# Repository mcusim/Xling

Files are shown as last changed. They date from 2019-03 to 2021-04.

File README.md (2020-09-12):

# Xling, a pocket demon



This is a little tamagotchi-like toy I've created for my wife. I used to think
that this is how a modern Tamagotchi could look like initially. However, it can
also be used as a battery-powered DIY platform to experiment with FreeRTOS and
graphics.

## Specifications

  * 35x47mm board
  * Monochrome OLED 128x64px
  * Low energy consumption (~20mA @ active, 0.75mA @ sleep)
  * Hand-soldering friendly (TQFP-44 0.8mm pitch, smallest is 0603)
  * 3D-printable case
  * Open Source Hardware/Firmware

## Hardware

  * ATmega1284P 8-bit AVR MCU with 128 KiB flash and 16 KiB SRAM
  * SH1106G display controller
  * MCP73831 charge controller
  * AP3401 DC-DC buck converter
  * 400mAh 3.7V Li-Po battery (~26h @ active, ~30 days @ sleep)
  * Load-sharing circuit (can be powered by USB or battery, like a smartphone)
  * KiCad 5.1.0 project for schematic and board designs
  * Released under CERN-OHL-W v2 (Rev. 4) and CC-BY-SA (before Rev. 4)



## Software

Please, note that the software part of the project isn't finished yet!

  * Shows a frame time, energy left and a battery charged status
  * Animation with Exy-in-the-bottle, a "personal daemon"
  * Programmed in C99 using the FreeRTOS kernel modified for ATmega1284P
  * There are three tasks only: Display, Battery Monitor and Sleep Mode
  * Released under GNU GPLv3+

## Website and Contact

Hackaday.io project: https://hackaday.io/project/165726-xling    
Email: dsl AT mcusim DOT org    
Dmitry Salychev

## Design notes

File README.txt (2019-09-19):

3d_models	.STEP and .WRL model files for all footprints
datasheets	data sheets for components used
gerber		final production files
images		SVG images and 3D board renders
lib_sch		schematic symbols
lib_fp.pretty	footprints
pdf		schematics, board layouts, dimension drawings

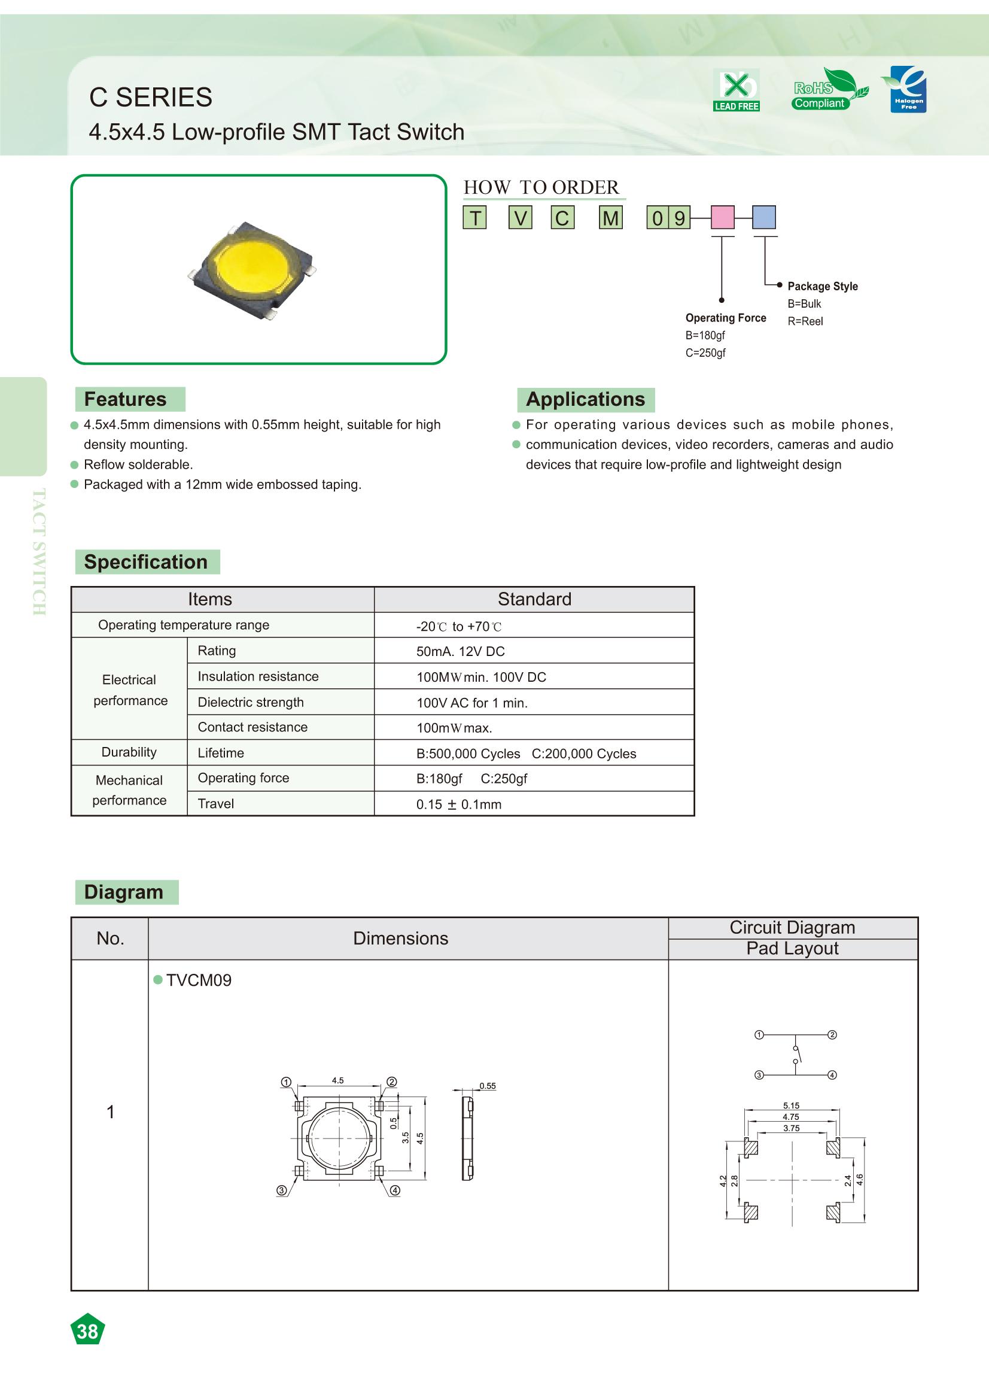
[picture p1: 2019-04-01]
hardware/datasheets/switch/TVCM09BB.jpg

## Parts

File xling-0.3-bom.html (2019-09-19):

Ref | Qnty | Value | Part | Footprint | Description | Vendor | Model
C1, C3, C4, C7, C10, C12 | 6 | 100nF | xling:C | Xling Footprints:C_0603_1608Metric |  |  | CL10B104KO8NNNC
C2, C11, C17, C18, C19, C20, C21 | 7 | 4.7uF | xling:C | Xling Footprints:C_0603_1608Metric |  |  | CL10A475KQ8NNNC
C5, C6, C16, C22 | 4 | 22pF | xling:C | Xling Footprints:C_0603_1608Metric |  |  | CL10C220JB8NNNC
C8, C9 | 2 | 0.22uF | xling:C | Xling Footprints:C_0603_1608Metric |  |  | CL10B224KO8NNNC
C13, C14, C15 | 3 | 4.7nF | xling:C | Xling Footprints:C_0603_1608Metric |  |  | CL10B472KB8NNNC
D1 | 1 | 1N5819 | xling:1N5818 | Xling Footprints:D_SOD-123 |  |  | 1N5819HW-7-F
J1 | 1 | ISP | xling:Conn_02x03_Odd_Even | Xling Footprints:Molex_Pico-Lock_504050-0691_1x06-1MP_P1.50mm_Horizontal |  |  | 504050-0691
J2 | 1 | USB_OTG | xling:USB_OTG | Xling Footprints:USB_Micro-B_Molex-105017-0001 |  |  | 105017-0001
J3 | 1 | Battery | xling:Conn_01x02 | Xling Footprints:Battery_SMD_pads_1x02_HandSoldering
L1 | 1 | 10uH | xling:L | Xling Footprints:L_1210_3225Metric |  |  | B82422A1103K100
L2 | 1 | 2.2uH | xling:L | Xling Footprints:L_1210_3225Metric |  |  | NLV32T-2R2J-PF
OH1 | 1 | OpenHardwareLogo | xling:OpenHardwareLogo | Xling Footprints:oshw
Q1 | 1 | NTR0202PL | xling:NTR2101P | Xling Footprints:SOT-23 |  |  | NTR0202PLT1G
R1, R2 | 2 | 1K | xling:R | Xling Footprints:R_0603_1608Metric |  |  | CRCW06031K00JNTABC
R3, R8, R9, R10, R11, R13 | 6 | 100K | xling:R | Xling Footprints:R_0603_1608Metric |  |  | 0603SAJ0104T5E
R4, R5, R6, R7, R12, R14, R15 | 7 | 510K | xling:R | Xling Footprints:R_0603_1608Metric |  |  | 0603SAJ0514T5E
R16 | 1 | 2.55K | xling:R | Xling Footprints:R_0603_1608Metric |  |  | 0603SAF2551T5E
R17, R18 | 2 | 110K | xling:R | Xling Footprints:R_0603_1608Metric |  |  | 0603SAF1103T5E
R19, R20 | 2 | 10K | xling:R | Xling Footprints:R_0603_1608Metric |  |  | 0603SAJ0103T5E
SW1, SW2, SW3 | 3 | BTN | xling:SW_Push | Xling Footprints:SW_Tact_4.5x4.5mm_TVCM09BB_Low_Profile |  |  | TVCM09BB
U1 | 1 | REX012864L | xling:REX012864L | Xling Footprints:DisplayPin_1x30_P0.7mm |  |  | REX012864LYAP3N00000
U2 | 1 | ATmega1284P-AU | xling:ATmega1284P-AU | Xling Footprints:TQFP-44_10x10mm_P0.8mm | 20MHz, 128kB Flash, 16kB SRAM, 4kB EEPROM, JTAG, TQFP-44 |  | ATMEGA1284P-AU
U3 | 1 | MCP73831 | xling:MCP73831 | Xling Footprints:MCP73831_SOT_23 |  |  | MCP73831T-2ATI/OT
U4 | 1 | AP3401_TSOT26 | xling:AP3401_TSOT26 | Xling Footprints:AP3401_TSOT26 | 1.5MHz, 1A DC-DC Buck Converter |  | AP3401KTTR-G1
Y1 | 1 | 12MHz | xling:Crystal_GND24 | Xling Footprints:Crystal_SMD_CFPX-104-4Pin_5x3.2mm | Four pin crystal, GND on pins 2 and 4 |  | LFXTAL032878BULK

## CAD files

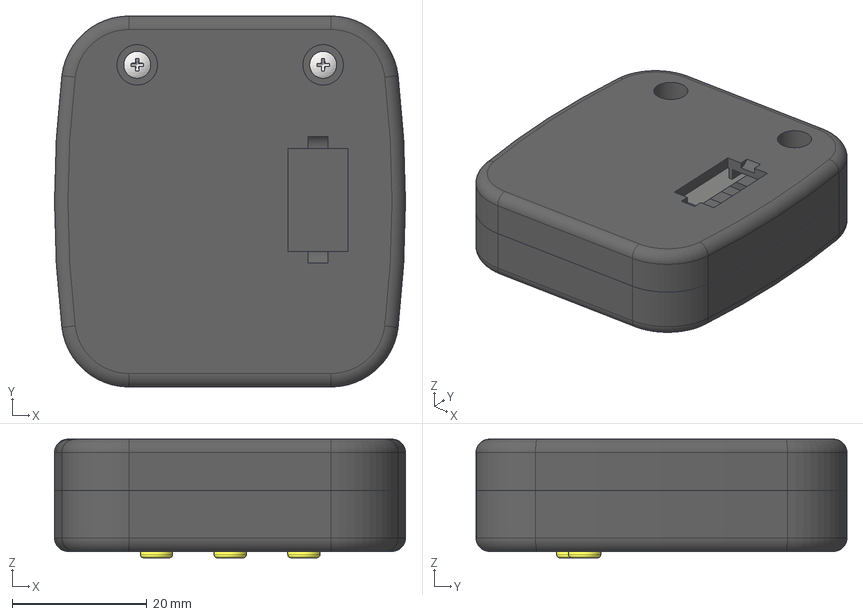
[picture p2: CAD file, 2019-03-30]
3d_models/xling_assembled_model.fcstd
52.0 x 55.0 x 17.6 mm
Display
Bottom_part
Top_part
Buttons
Battery
Screw1
Screw2

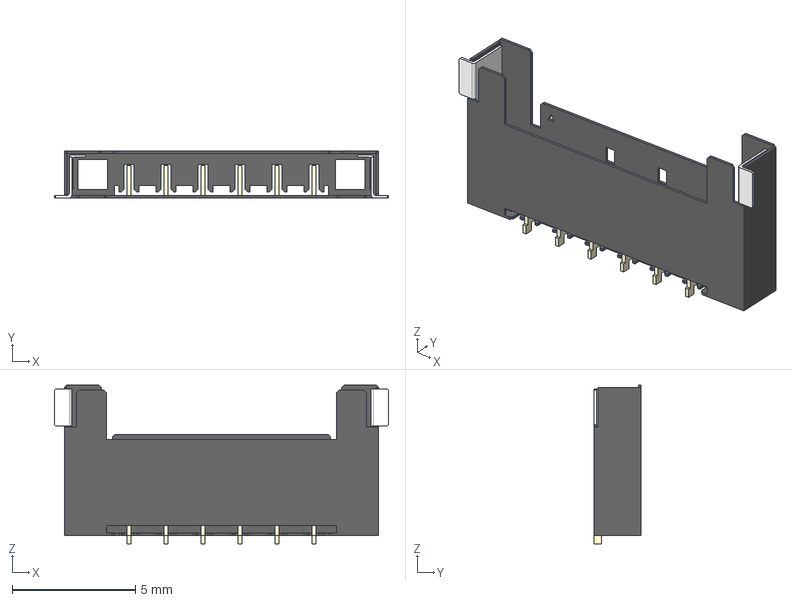
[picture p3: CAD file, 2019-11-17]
3d_models/packages/Molex_504050-0691.stp
13.5 x 1.90 x 6.44 mm

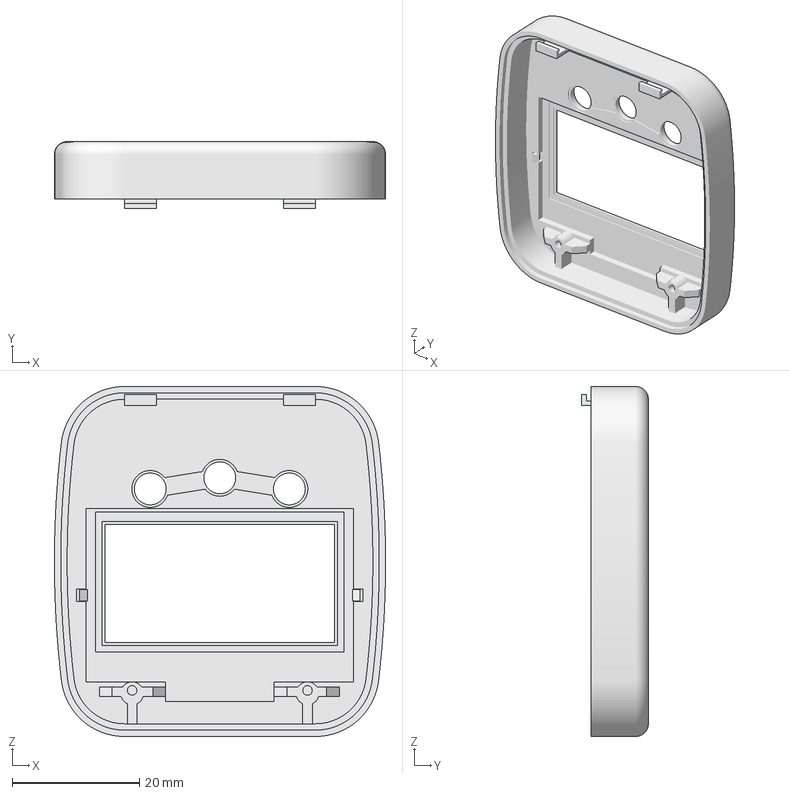
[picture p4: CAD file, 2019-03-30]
3d_models/Top_case_v8.FCStd
52.0 x 10.5 x 55.0 mm

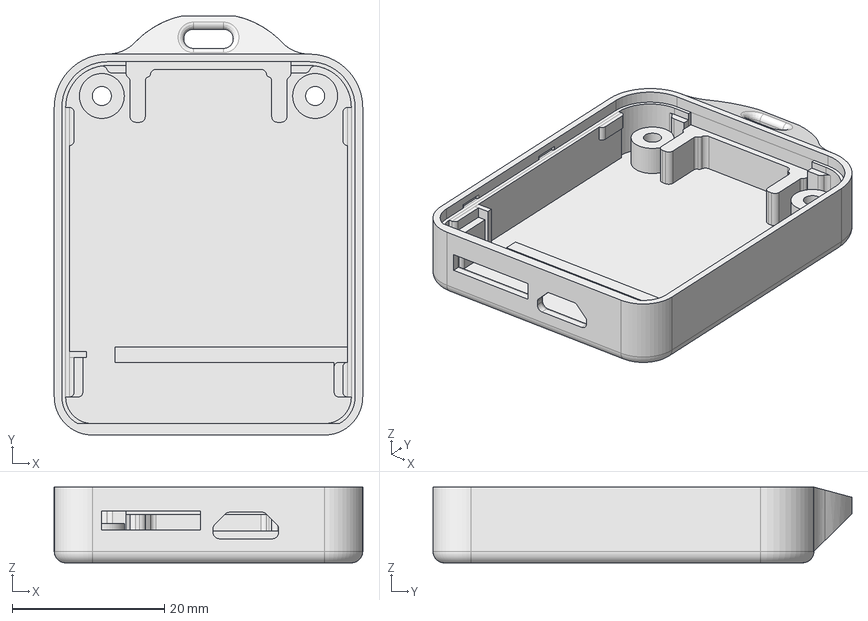
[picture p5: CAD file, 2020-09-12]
case/Bottom_case.FCStd
40.5 x 55.0 x 9.95 mm

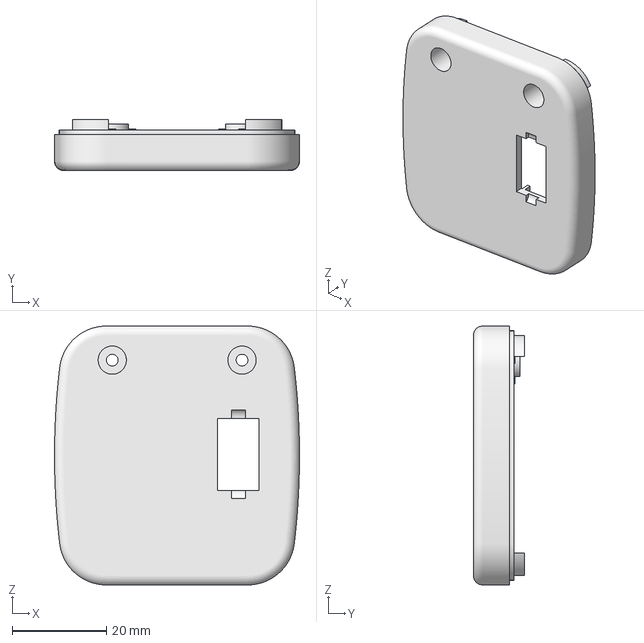
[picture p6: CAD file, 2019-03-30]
hardware/3d_models/Bottom_case_v8.FCStd
52.0 x 10.9 x 55.0 mm

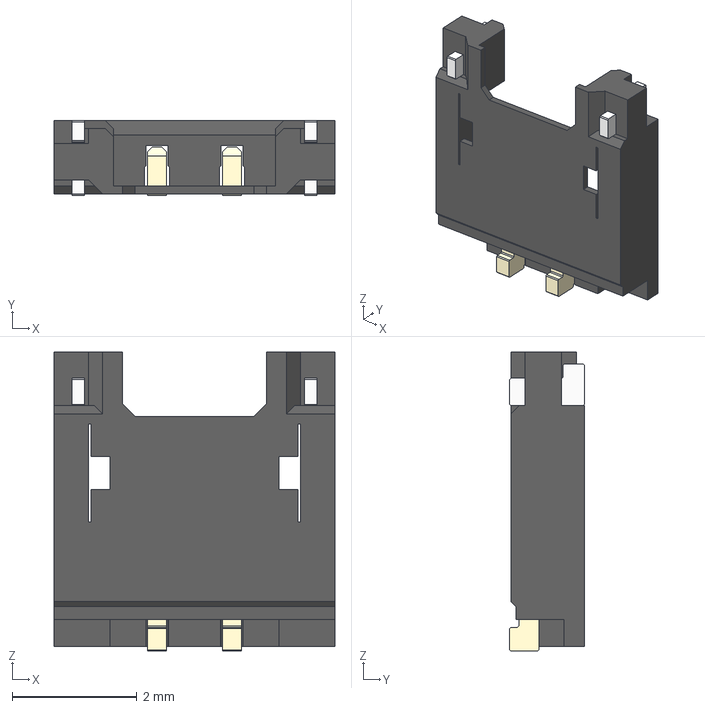
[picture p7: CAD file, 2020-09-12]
hardware/3d_models/packages/Molex-202656-0021.stp
4.50 x 1.20 x 4.79 mm

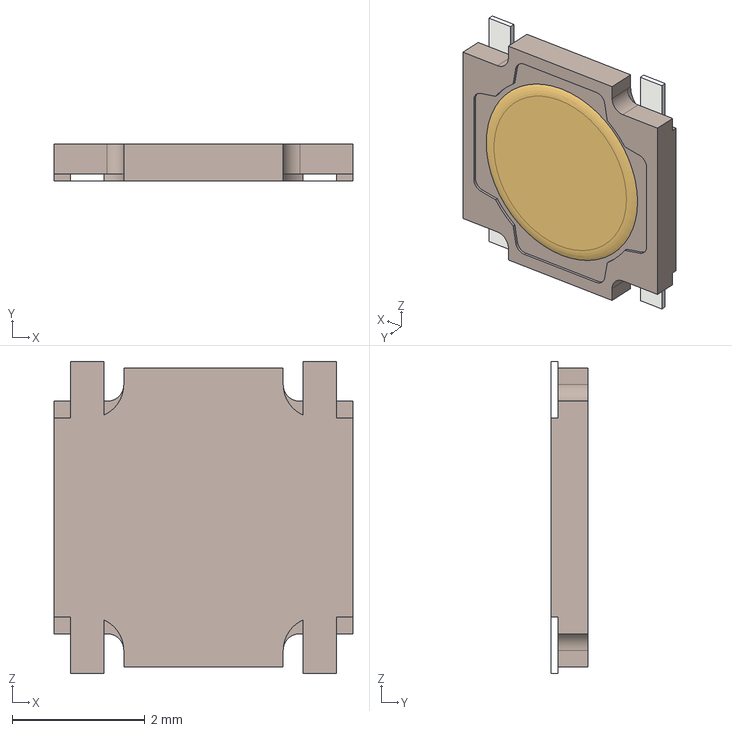
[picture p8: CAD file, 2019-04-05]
3d_models/packages/Switch_TVCM09.stp
4.50 x 0.55 x 4.70 mm

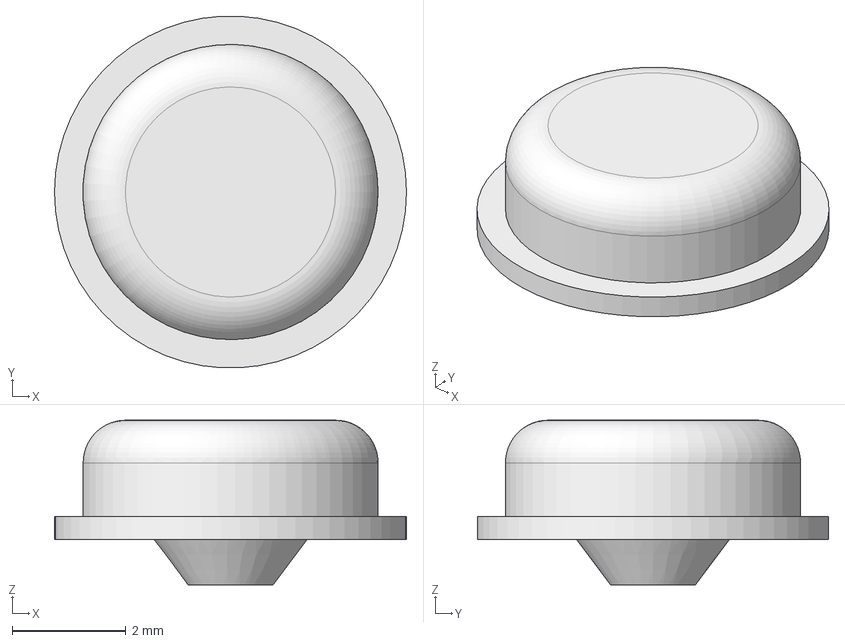
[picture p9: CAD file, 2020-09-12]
case/Button.FCStd
6.20 x 6.19 x 2.90 mm

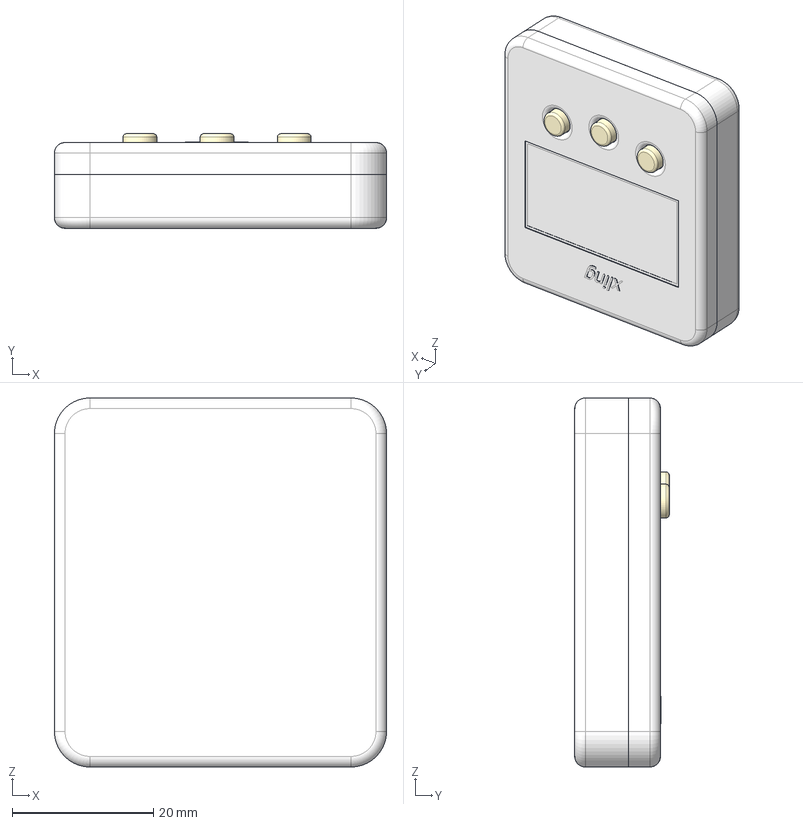
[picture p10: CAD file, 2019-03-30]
hardware/3d_models/Device_case_v9.FCStd
47.0 x 13.4 x 52.3 mm
\X2\041404380441043F043B04350439\X0\ DEP128064I-Y
\X2\041D04380436043D044F044F\X0\ \X2\0447043004410442044C\X0\ \X2\043A043E0440043F044304410430\X0\ v.9
\X2\0412043504400445043D044F044F\X0\ \X2\0447043004410442044C\X0\ \X2\043A043E0440043F044304410430\X0\ v.9
\X2\041F0435044704300442043D0430044F\X0\ \X2\043F043B043004420430\X0\ v.6
\X2\0410043A0442044304300442043E0440\X0\ KSC2
\X2\0410043A0442044304300442043E0440\X0\ KSC003
\X2\0410043A0442044304300442043E0440\X0\ KSC004
\X2\04140438043E0434\X0\ \X2\0428043E04420442043A0438\X0\
\X2\041A043E043D043204350440044204350440\X0\ 3\X2\0412\X0\ \X2\0432\X0\ 12\X2\0412\X0\
\X2\041C0438043A0440043E043A043E043D04420440043E043B043B04350440\X0\
\X2\041A0430044204430448043A0430\X0\ \X2\0438043D04340443043A044204380432043D043E044104420438\X0\
\X2\04140438043E0434\X0\ \X2\0428043E04420442043A0438\X0\001
USB_mini_B
\X2\041A043E043B043F04300447043A0438\X0\ \X2\043D0430\X0\ \X2\043A043D043E043F043A0438\X0\
\X2\041104300442043004400435044F\X0\ LP403035

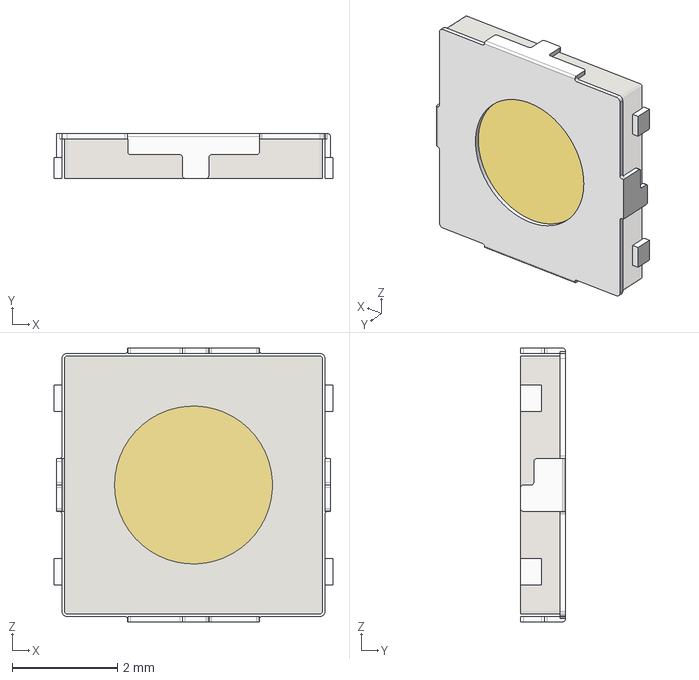
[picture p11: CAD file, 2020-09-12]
hardware/3d_models/packages/TVCU11BB.stp
5.30 x 0.85 x 5.20 mm

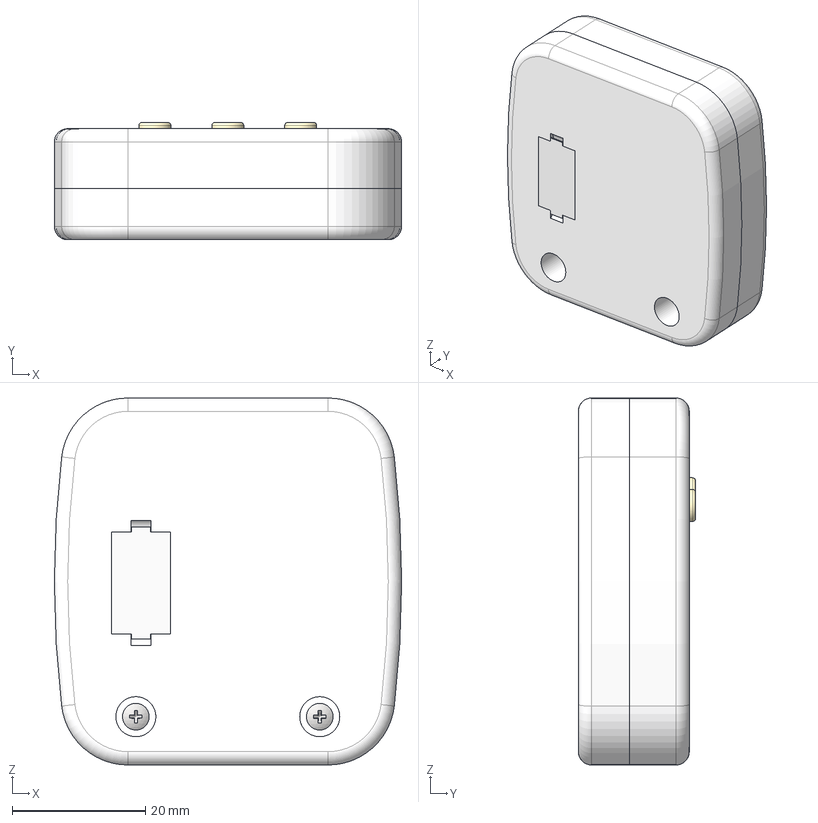
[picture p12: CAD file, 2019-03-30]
3d_models/xling_case_v8.FCStd
52.0 x 17.6 x 55.0 mm
\X2\041404380441043F043B04350439\X0\ DEP128064I-Y
\X2\041D04380436043D044F044F\X0\ \X2\0447043004410442044C\X0\ \X2\043A043E0440043F044304410430\X0\ v.8
\X2\0412043504400445043D044F044F\X0\ \X2\0447043004410442044C\X0\ \X2\043A043E0440043F044304410430\X0\ v.8
\X2\041F0435044704300442043D0430044F\X0\ \X2\043F043B043004420430\X0\ v.6
\X2\0410043A0442044304300442043E0440\X0\ KSC2
\X2\0410043A0442044304300442043E0440\X0\ KSC003
\X2\0410043A0442044304300442043E0440\X0\ KSC004
\X2\04140438043E0434\X0\ \X2\0428043E04420442043A0438\X0\
\X2\041A043E043D043204350440044204350440\X0\ 3\X2\0412\X0\ \X2\0432\X0\ 12\X2\0412\X0\
\X2\041C0438043A0440043E043A043E043D04420440043E043B043B04350440\X0\
\X2\041A0430044204430448043A0430\X0\ \X2\0438043D04340443043A044204380432043D043E044104420438\X0\
\X2\04140438043E0434\X0\ \X2\0428043E04420442043A0438\X0\001
\X2\042004300437044A0435043C\X0\ ISP
USB_mini_B
\X2\041A043E043B043F04300447043A0438\X0\ \X2\043D0430\X0\ \X2\043A043D043E043F043A0438\X0\
\X2\041104300442043004400435044F\X0\ LP403035
\X2\041A0440044B0448043A0430\X0\ \X2\044004300437044A0435043C0430\X0\ ISP
\X2\04120438043D0442\X0\ ST2.2x6,5-C-H \X2\0413041E04210422\X0\ \X2\0420\X0\ \X2\04180421041E\X0\ 7049-93
\X2\04120438043D0442\X0\ ST2.2x6,5-C-H \X2\0413041E04210422\X0\ \X2\0420\X0\ \X2\04180421041E\X0\ 7049-094

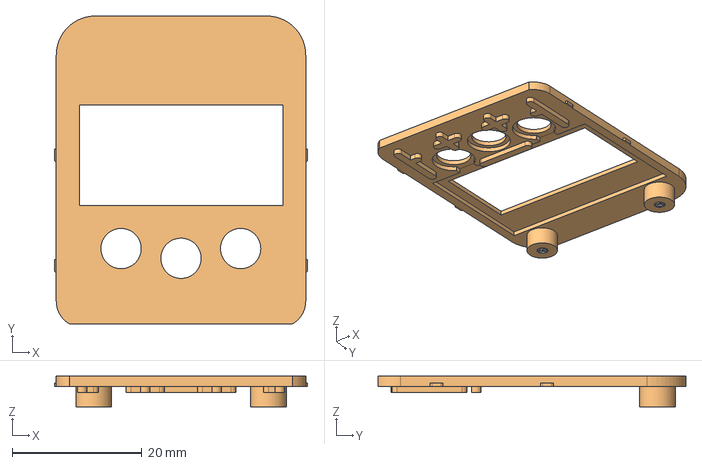
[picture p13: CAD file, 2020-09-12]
case/Top_case.FCStd
39.0 x 47.4 x 4.75 mm
Thread

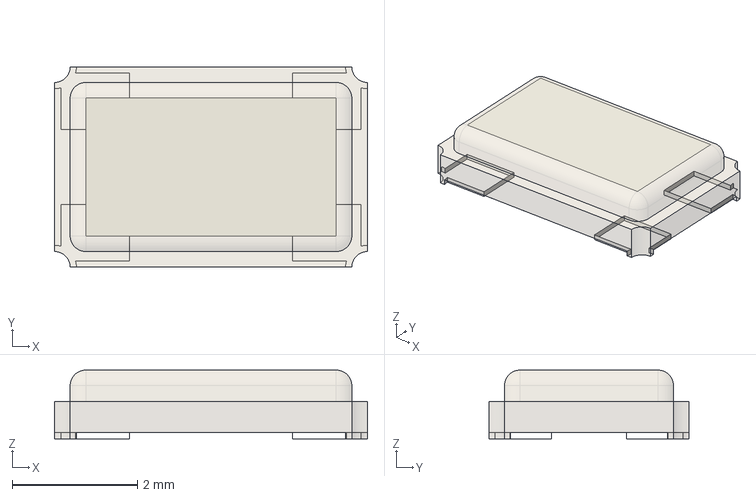
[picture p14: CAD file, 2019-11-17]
hardware/3d_models/packages/SFPX-104.stp
5.00 x 3.20 x 1.10 mm

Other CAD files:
3d_models/Device_case_v8.FCStd
case/3d_print/Bottom_case.amf
case/3d_print/Bottom_case.stl
case/3d_print/Button.amf
case/3d_print/Button.stl
case/3d_print/Top_case.amf
case/3d_print/Top_case.stl
hardware/3d_models/Device_case_v8.FCStd
hardware/3d_models/packages/AP3401.stp
hardware/3d_models/packages/MCP73831.stp

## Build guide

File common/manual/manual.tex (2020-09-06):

%-
% SPDX-License-Identifier: GPL-3.0-or-later
%
% This file is part of a firmware for Xling, a tamagotchi-like toy.
%
% Copyright (c) 2019 Dmitry Salychev
%
% Xling firmware is free software: you can redistribute it and/or modify
% it under the terms of the GNU General Public License as published by
% the Free Software Foundation, either version 3 of the License, or
% (at your option) any later version.
%
% Xling firmware is distributed in the hope that it will be useful,
% but WITHOUT ANY WARRANTY; without even the implied warranty of
% MERCHANTABILITY or FITNESS FOR A PARTICULAR PURPOSE.  See the
% GNU General Public License for more details.
%
% You should have received a copy of the GNU General Public License
% along with this program.  If not, see <https://www.gnu.org/licenses/>.

%
% LaTeX sources of the Xling User Manual.
%
\documentclass[11pt,a4paper,twoside]{report}

%
% Packages.
%
%\usepackage{showframe}
\usepackage[utf8]{inputenc}
\usepackage{geometry}
\usepackage{graphicx}
\usepackage{caption}
\usepackage{subcaption}
\usepackage{blindtext}
\usepackage{layout}
\usepackage{hyperref}
%\usepackage{mfirstuc}			% helps to make First Capital Letters.
\usepackage[nameinlink]{cleveref}	% helps to make Capitalized references.

%
% Page configuration.
%
% NOTE: See http://www.texdoc.net/texmf-dist/doc/latex/geometry/geometry.pdf
%       for details.
%
\geometry{
	includehead,	% head will be included into total body
	includefoot,	% foot will be included into total body
	inner=72pt,	% left margin (between paper and total body)
	outer=72pt,	% right margin (between paper and total body)
	top=50pt,	% top margin (between paper and total body)
	bottom=50pt,	% bottom margin (between paper and total body)
}

%
% Hyperlinks setup.
%
% NOTE: See https://en.wikibooks.org/wiki/LaTeX/Hyperlinks for details.
%
% NOTE: See https://sunsite.icm.edu.pl/pub/CTAN/macros/latex/contrib/
%	cleveref/cleveref.pdf for details.
%
\hypersetup{
	bookmarks=true,		% create PDF bookmarks/outline?
	hidelinks,		% hide links (removing color and border)
}

%
% Graphicx package setup.
%
\graphicspath{ {./images/} }

\renewcommand{\familydefault}{\sfdefault}
\everymath={\sf}

\title{Xling User Manual}
\author{Dmitry Salychev}
\setcounter{tocdepth}{2}

% -----------------------------------------------------------------------------
% Document
% -----------------------------------------------------------------------------
\begin{document}

\maketitle
\tableofcontents

\chapter*{Introduction}
Congratulations! It looks like you bought a kit to build Xling,
a tamagotchi-like toy, or decided to follow your own way to assemble and
program it from scratch. This manual will help you anyway. Chapters of the
document are placed in a logical order to make the device ready to be
programmed, tested and populated with your own firmware.
\\
\\
\textbf{\Cref{chap:safety}} should be read first in order to understand how to
build and use Xling safely and prevent any damage.
\textbf{\Cref{chap:assembling_device}} is a good place to start if you're
going to build the device from scratch and its
\textbf{\Cref{sec:board_from_prebuilt_kit}} will help you to finish the
pre-built Xling. \textbf{\Cref{chap:testing_device}}
will cover several topics about understanding your device is built correctly
and ready to be used.
\textbf{\Cref{chap:building_firmware}} explains how to get sources of the basic
Xling firmware\footnote{https://github.com/mcusim/Xling}, build it and upload
to the device.
\\
\\
Initially, Xling was meant to be a simple, but well made toy for my wife which
should be fun and particularly easy to made. And it turned out exactly as I
imagined with 8-bit AVR microcontroller, 128x64 OLED display and a battery
charging circuit. Its PCB design files and source code of the firmware are
distributed under open source licenses\footnote{CERN-OHL-W v2 and GNU GPLv3+
accordingly} which makes this toy a perfect candidate to study from hardware
and software point of view. You might find it even more interesting because
FreeRTOS, a well known and probably the most popular real-time operating system,
is used to power Xling.
\\
\\
Enjoy.
\\
\\
Regards\\
Dmitry Salychev\\
dsl@MCUSim.org

% -----------------------------------------------------------------------------
% Chapter: Safety.
% -----------------------------------------------------------------------------
\chapter{Safety}
\label{chap:safety}
Please, note that Xling is an open hardware DIY\footnote{do-it-yourself}
electronic toy which hasn't been certified against any electrical safety
standards. However, it doesn't mean that you should ignore rules which help
to prevent damage to your property or health.
\\
\\
Safety rules are:
\begin{enumerate}
	\item
	Do not try to assemble, repair or disassemble Xling yourself if you
	don't know how to work with laboratory equipment like soldering irons,
	hot air guns, desolderings tools, etc.
	\item
	Do not damage Xling or its parts. It carries a fragile OLED display
	which is made using glass. LiPo battery should not be damaged or
	disassembled.
	\item
	Do not try to change firmware of the device if you aren't sure that
	your changes won't break battery charging circuit\footnote{if in doubt,
	ask dsl@MCUSim.org} work.
	\item
	Xling doesn't have a protection against water or dust. You should be
	careful with using it outdoor.
\end{enumerate}

% -----------------------------------------------------------------------------
% Chapter: Assembling the device.
% -----------------------------------------------------------------------------
\chapter{Assembling the device}
\label{chap:assembling_device}
Xling has been designed to be a device easy to made. It means that almost
everything\footnote{except PCB itself, probably} can be done on your own.
For example, if you've a decent 3D printer and some experience printing things
from PETG, you'll be able to produce a case for Xling. If you've a good
soldering iron, a hot air gun, and an ability to solder components as small
as 0603, you'll be able to assemble PCB then.
\\
\\
The following sections are supposed to help you taking steps from gathering
components from the BOM and checking that you've all of the required tools and
equipment to assemble the board to several final steps to finish the board by
chosing and soldering a suitable LiPo battery in order to support an idea
behind this chapter which is to let you start from any point depending on
what you've at your hands.

\section{Overview of the Xling kit}
\label{sec:overview_of_the_kit}

\section{Starting from scratch}
\label{sec:board_from_scratch}
[ section under construction ]

\section{Assembling the board}
\label{sec:board_from_kit}
[ section under construction ]

\section{Finishing the board}
\label{sec:board_from_prebuilt_kit}
This section will guide you through a process of finishing the Xling PCB
to make it ready to be tested and placed into a 3D printed case. It is usually
a convenient way to get a toy ready in only a fraction of that amount of time
which might be necessary to build it from scratch.
\begin{figure}[h]
	\centering
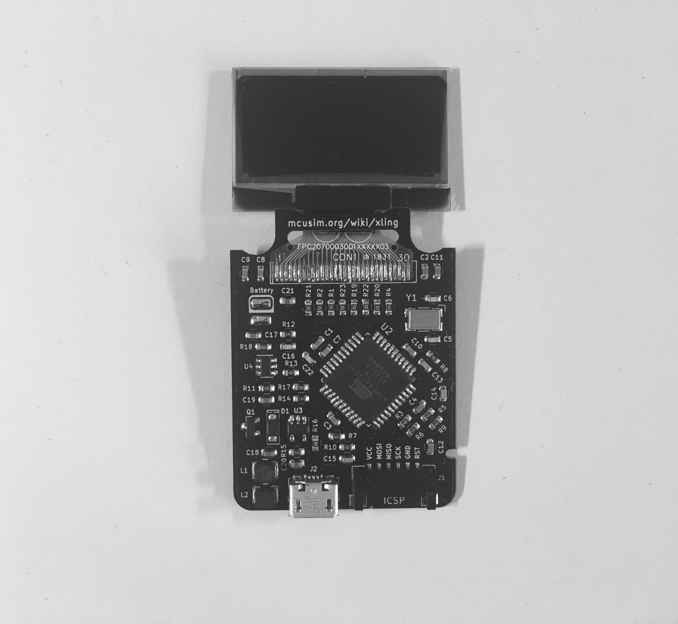
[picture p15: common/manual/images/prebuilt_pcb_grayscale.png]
	
	\caption{Pre-built Xling PCB}
\end{figure}

% -----------------------------------------------------------------------------
% Chapter: Testing the device.
% -----------------------------------------------------------------------------
\chapter{Testing the device}
\label{chap:testing_device}
[ section under construction ]

% -----------------------------------------------------------------------------
% Chapter: Building firmware.
% -----------------------------------------------------------------------------
\chapter{Building and uploading firmware}
\label{chap:building_firmware}
[ section under construction ]

\end{document}

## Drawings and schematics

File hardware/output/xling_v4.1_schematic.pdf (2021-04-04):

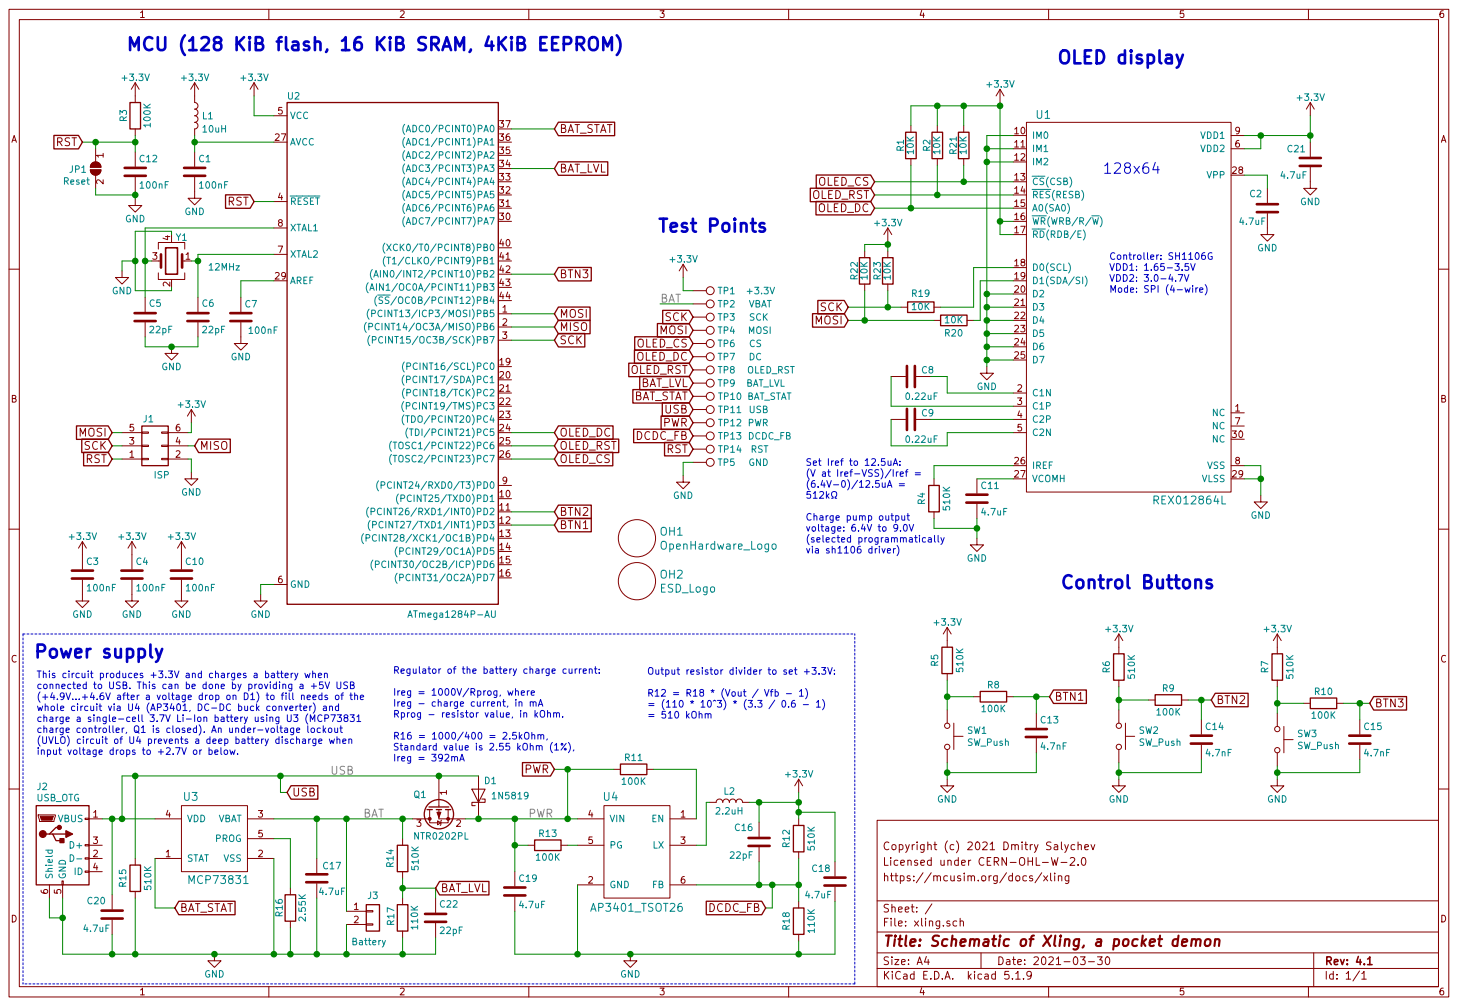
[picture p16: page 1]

MCU (128 KiB flash, 16 KiB SRAM, 4KiB EEPROM)
+3.3V GND
100nF GND
RST

BAT Regulator of the battery charge current:

VDD2: 3.0-4.7V Mode: SPI (4-wire) Set Iref to 12.5uA: (V at Iref-VSS)/Iref =

Output resistor divider to set +3.3V:

This circuit produces +3.3V and charges a battery when
connected to USB. This can be done by providing a +5V USB
(+4.9V...+4.6V after a voltage drop on D1) to fill needs of the
whole circuit via U4 (AP3401, DC-DC buck converter) and
charge a single-cell 3.7V Li-Ion battery using U3 (MCP73831
charge controller, Q1 is closed). An under-voltage lockout
(UVLO) circuit of U4 prevents a deep battery discharge when
input voltage drops to +2.7V or below.

Ireg = 1000V/Rprog, where
Ireg - charge current, in mA
Rprog - resistor value, in kOhm.

File: xling.sch Sheet: / https://mcusim.org/docs/xling

Id: 1/1 Title: Schematic of Xling, a pocket demon

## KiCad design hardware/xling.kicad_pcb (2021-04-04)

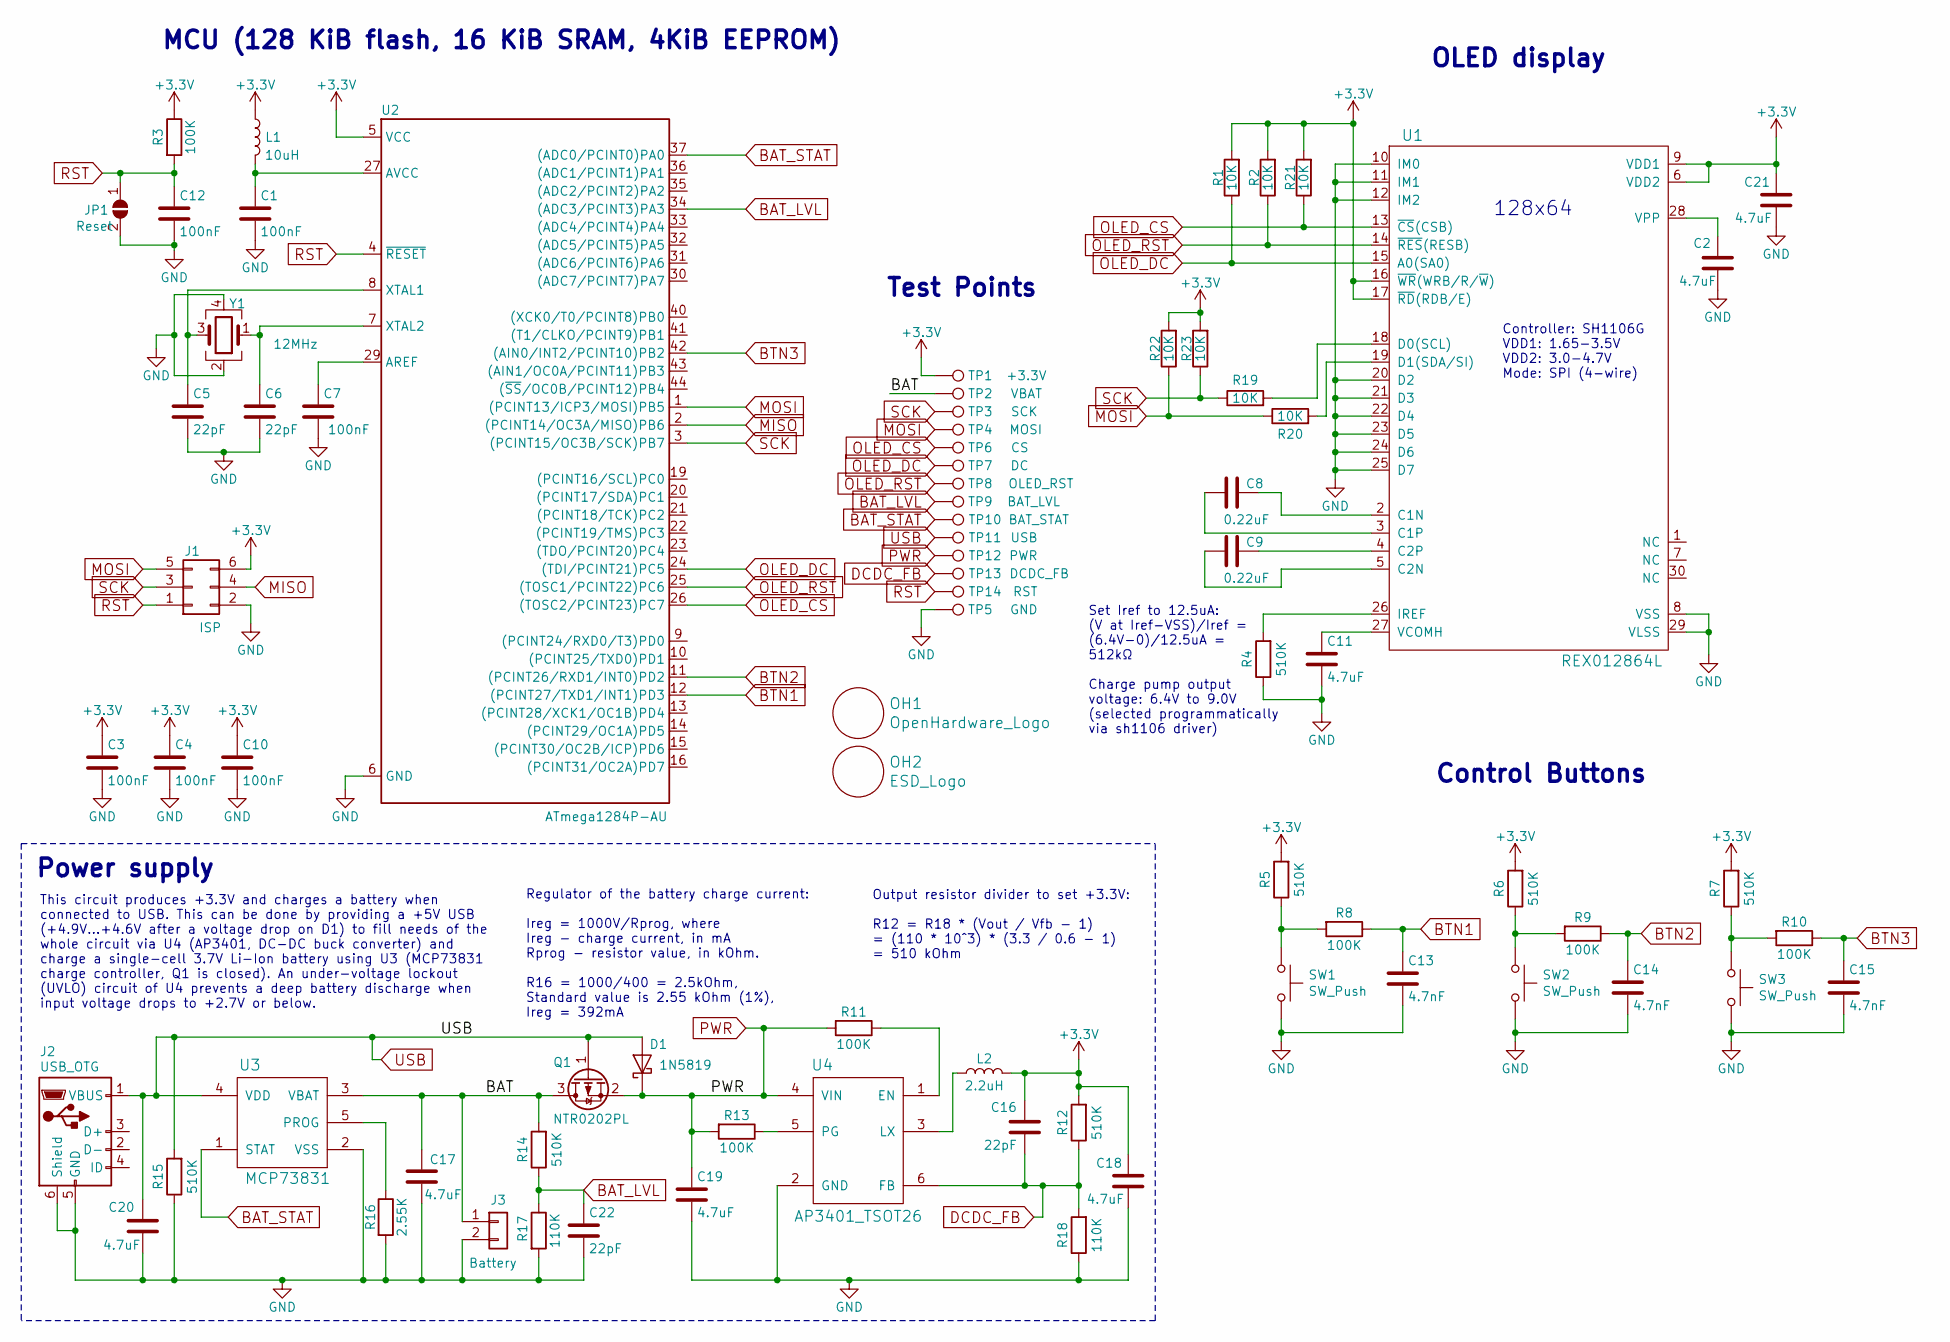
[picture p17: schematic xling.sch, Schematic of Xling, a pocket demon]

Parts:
C1, C3, C4, C7, C10, C12: 100nF; C_0603_1608Metric; MPN CL10B104KO8NNNC
C2, C11, C17, C18, C19, C20, C21: 4.7uF; C_0603_1608Metric; MPN CL10A475KQ8NNNC
C5, C6, C16, C22: 22pF; C_0603_1608Metric; MPN CL10C220JB8NNNC
C8, C9: 0.22uF; C_0603_1608Metric; MPN CL10B224KO8NNNC
C13, C14, C15: 4.7nF; C_0603_1608Metric; MPN CL10B472KB8NNNC
D1: 1N5819; D_SOD-123; MPN 1N5819HW-7-F
J1: ISP; Molex_Pico-Lock_504050-0691_1x06-1MP_P1.50mm_Horizontal; MPN 504050-0691
J2: USB_OTG; USB_Micro-B_Molex-105017-0001; MPN 105017-0001
J3: Battery; Battery_SMD_pads_1x02_HandSoldering; MPN N/A
JP1: Reset; SolderJumper-2_P1.3mm_Open_Pad1.0x1.5mm
L1: 10uH; L_1210_3225Metric; MPN B82422A1103K100
L2: 2.2uH; L_1210_3225Metric; MPN NLV32T-2R2J-PF
OH1: OpenHardware_Logo; OSHW-Logo_5.7x6mm_SilkScreen
OH2: ESD_Logo; ESD-Logo_6.6x6mm_SilkScreen
Q1: NTR0202PL; SOT-23; MPN NTR0202PLT1G
R1, R2, R19, R20, R21, R22, R23: 10K; R_0603_1608Metric; MPN 0603SAJ0103T5E
R3, R8, R9, R10, R11, R13: 100K; R_0603_1608Metric; MPN 0603SAJ0104T5E
R4, R5, R6, R7, R12, R14, R15: 510K; R_0603_1608Metric; MPN 0603SAJ0514T5E
R16: 2.55K; R_0603_1608Metric; MPN 0603SAF2551T5E
R17, R18: 110K; R_0603_1608Metric; MPN 0603SAF1103T5E
SW1, SW2, SW3: SW_Push; SW_Tact_4.5x4.5mm_TVCM09BB_Low_Profile; MPN TVCM09BB
TP1: +3.3V; TestPoint_Pad_D0.5mm
TP2: VBAT; TestPoint_Pad_D0.5mm
TP3: SCK; TestPoint_Pad_D0.5mm
TP4: MOSI; TestPoint_Pad_D0.5mm
TP5: GND; TestPoint_Pad_D1.0mm
TP6: CS; TestPoint_Pad_D0.5mm
TP7: DC; TestPoint_Pad_D0.5mm
TP8: OLED_RST; TestPoint_Pad_D0.5mm
TP9: BAT_LVL; TestPoint_Pad_D0.5mm
TP10: BAT_STAT; TestPoint_Pad_D0.5mm
TP11: USB; TestPoint_Pad_D0.5mm
TP12: PWR; TestPoint_Pad_D0.5mm
TP13: DCDC_FB; TestPoint_Pad_D0.5mm
TP14: RST; TestPoint_Pad_D0.5mm
U1: REX012864L; DisplayPin_1x30_P0.7mm; MPN REX012864LWAP3N00000
U2: ATmega1284P-AU; TQFP-44_10x10mm_P0.8mm; MPN ATMEGA1284P-AU
U3: MCP73831; MCP73831_SOT_23; MPN MCP73831T-2ATI/OT
U4: AP3401_TSOT26; MPN AP3401KTTR-G1
Y1: 12MHz; Crystal_SMD_CFPX-104-4Pin_5x3.2mm; MPN LFXTAL032878BULK

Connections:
+3V3: C3.1, C4.1, C10.1, C16.1, C18.1, C21.1, J1.6, L1.1, L2.2, R1.2, R2.2, R3.1, R5.2, R6.2, R7.2, R12.2, R21.2, R22.2, R23.2, TP1.1, U1.6 (VDD2), U1.9 (VDD1), U1.16 (~WR~(WRB/R/~W~)), U1.17 (~RD~(RDB/E)), U2.5 (VCC), U2.17 (VCC), U2.38 (VCC)
/BAT: C17.1, J3.1, Q1.3 (D), R14.2, TP2.1, U3.3 (VBAT)
BAT_LVL: C22.2, R14.1, R17.1, TP9.1, U2.34 ((ADC3/PCINT3)PA3)
BAT_STAT: TP10.1, U2.37 ((ADC0/PCINT0)PA0), U3.1 (STAT)
BTN1: C13.1, R8.1, U2.12 ((PCINT27/TXD1/INT1)PD3)
BTN2: C14.1, R9.1, U2.11 ((PCINT26/RXD1/INT0)PD2)
BTN3: C15.1, R10.1, U2.42 ((AIN0/INT2/PCINT10)PB2)
DCDC_FB: C16.2, R12.1, R18.2, TP13.1, U4.6 (FB)
GND: C1.2, C2.2, C3.2, C4.2, C5.1, C6.1, C7.2, C10.2, C11.2, C12.2, C13.2, C14.2, C15.2, C17.2, C18.2, C19.2, C20.2, C21.2, C22.1, J1.2, J2.5 (GND), J2.6 (Shield), J3.2, JP1.2 (B), R4.1, R15.1, R16.2, R17.2, R18.1, SW1.2, SW2.2, SW3.2, TP5.1, U1.8 (VSS), U1.10 (IM0), U1.11 (IM1), U1.12 (IM2), U1.20 (D2), U1.21 (D3), U1.22 (D4), U1.23 (D5), U1.24 (D6), U1.25 (D7), U1.29 (VLSS), U2.6 (GND), U2.18 (GND), U2.28 (GND), U2.39 (GND), U3.2 (VSS), U4.2 (GND), Y1.2, Y1.4
MISO: J1.4, U2.2 ((PCINT14/OC3A/MISO)PB6)
MOSI: J1.5, R20.1, R22.1, TP4.1, U2.1 ((PCINT13/ICP3/MOSI)PB5)
unnamed: C1.1, L1.2, U2.27 (AVCC)
unnamed: C2.1, U1.28 (VPP)
unnamed: C5.2, U2.8 (XTAL1), Y1.3
unnamed: C6.2, U2.7 (XTAL2), Y1.1
unnamed: C7.1, U2.29 (AREF)
unnamed: C8.1, U1.2 (C1N)
unnamed: C8.2, U1.3 (C1P)
unnamed: C9.1, U1.4 (C2P)
unnamed: C9.2, U1.5 (C2N)
unnamed: C11.1, U1.27 (VCOMH)
unnamed: L2.1, U4.3 (LX)
unnamed: R4.2, U1.26 (IREF)
unnamed: R5.1, R8.2, SW1.1
unnamed: R6.1, R9.2, SW2.1
unnamed: R7.1, R10.2, SW3.1
unnamed: R11.1, U4.1 (EN)
unnamed: R13.1, U4.5 (PG)
unnamed: R16.1, U3.5 (PROG)
unnamed: R19.2, U1.18 (D0(SCL))
unnamed: R20.2, U1.19 (D1(SDA/SI))
OLED_CS: R21.1, TP6.1, U1.13 (~CS~(CSB)), U2.26 ((TOSC2/PCINT23)PC7)
OLED_DC: R1.1, TP7.1, U1.15 (A0(SA0)), U2.24 ((TDI/PCINT21)PC5)
OLED_RST: R2.1, TP8.1, U1.14 (~RES~(RESB)), U2.25 ((TOSC1/PCINT22)PC6)
PWR: C19.1, D1.1 (K), Q1.2 (S), R11.2, R13.2, TP12.1, U4.4 (VIN)
RST: C12.1, J1.1, JP1.1 (A), R3.2, TP14.1, U2.4 (~RESET)
SCK: J1.3, R19.1, R23.1, TP3.1, U2.3 ((PCINT15/OC3B/SCK)PB7)
USB: C20.1, D1.2 (A), J2.1 (VBUS), Q1.1 (G), R15.2, TP11.1, U3.4 (VDD)

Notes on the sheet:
Power supply
Controller: SH1106G VDD1: 1.65-3.5V VDD2: 3.0-4.7V Mode: SPI (4-wire)
Output resistor divider to set +3.3V: R12 = R18 * (Vout / Vfb - 1) = (110 * 10^3) * (3.3 / 0.6 - 1) = 510 kOhm
OLED display
Control Buttons
128x64
MCU (128 KiB flash, 16 KiB SRAM, 4KiB EEPROM)
Test Points
This circuit produces +3.3V and charges a battery when connected to USB. This can be done by providing a +5V USB (+4.9V...+4.6V after a voltage drop on D1) to fill needs of the whole circuit via U4 (AP3401, DC-DC buck converter) and charge a single-cell 3.7V Li-Ion battery using U3 (MCP73831 charge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
Set Iref to 12.5uA: (V at Iref-VSS)/Iref = (6.4V-0)/12.5uA = 512kΩ Charge pump output voltage: 6.4V to 9.0V (selected programmatically via sh1106 driver)
Regulator of the battery charge current: Ireg = 1000V/Rprog, where Ireg - charge current, in mA Rprog - resistor value, in kOhm. R16 = 1000/400 = 2.5kOhm, Standard value is 2.55 kOhm (1%), Ireg = 392mA

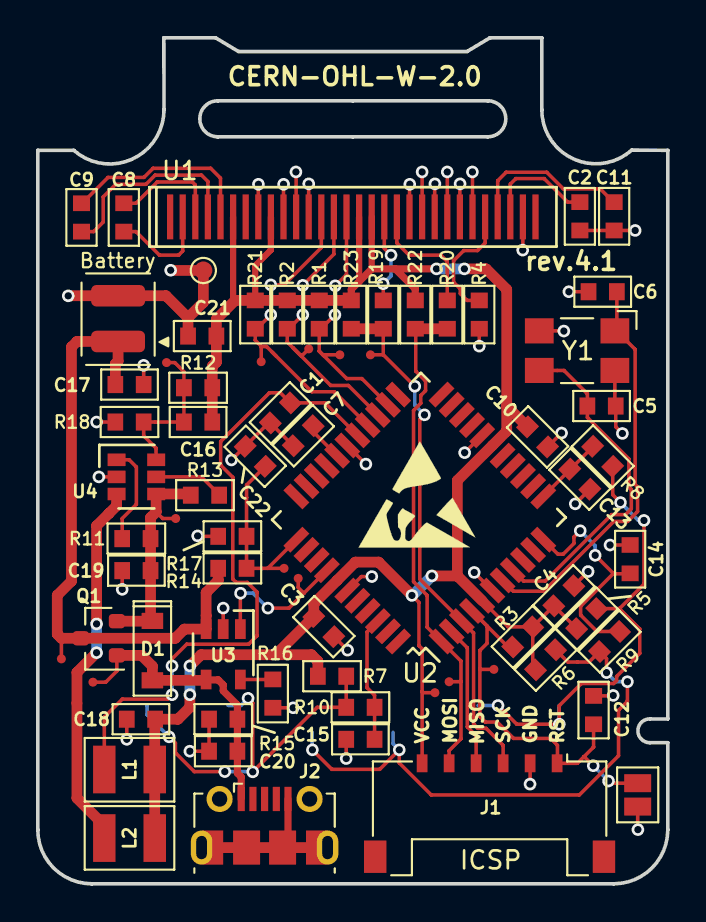
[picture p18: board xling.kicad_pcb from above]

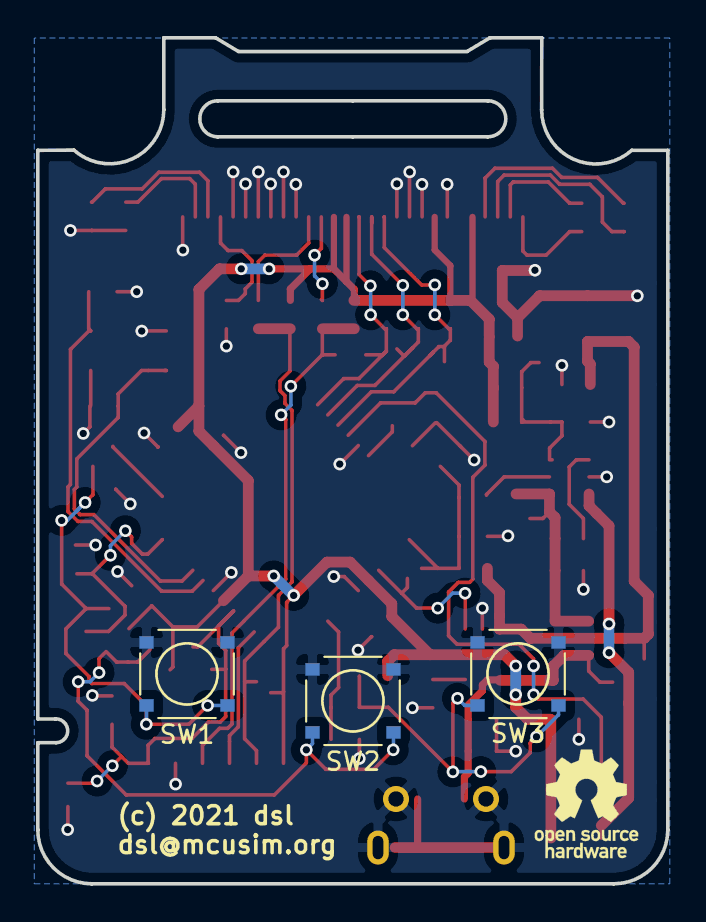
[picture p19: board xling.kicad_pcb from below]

Board: 2 copper layers, 35.0 x 47.0 mm, 77 parts (4 on the bottom side), 38 nets.

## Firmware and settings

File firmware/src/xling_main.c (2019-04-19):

/*
 * Copyright (c) 2017, 2018, The MCUSim Contributors
 * All rights reserved.
 *
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
 * Main file of the Xling firmware.
 */
#define F_CPU			12000000UL	/* CPU clock frequency */
#define TWI_CLOCK		400000L		/* TWI clock frequency */

#include <stdint.h>
#include <stdio.h>
#include <limits.h>
#include <avr/io.h>
#include <avr/interrupt.h>
#include <avr/pgmspace.h>
#include <util/delay.h>

#include "xling/twi.h"
#include "xling/luci.h"
#include "xling/hw/ssd1309.h"

#define SET_BIT(byte, bit)	((byte)|=(1UL<<(bit)))
#define CLEAR_BIT(byte, bit)	((byte)&=~(1UL<<(bit)))
#define IS_SET(byte, bit)	(((byte)&(1UL<<(bit)))>>(bit))

#define BTN1			PD0
#define BTN2			PD1
#define BTN3			PD2
#define OLED_RES		PD3
#define OLED_PWR		PD4

#define FRAME_ITER		5
#define FRAME_DIV		100000UL

/* Static variables */
static struct XG_TWI twi;
static struct XG_SSD1309 display;
static volatile uint32_t ms = 0;

/* Declarations of the local functions */
static void timer2_init(void);

int main(void)
{
	uint32_t i, j, frames;
	uint32_t delay_ms;
	char textbuf[32];

	/* Bit-bang TWI configuration */
	twi.port = (uint8_t *)0x28;	/* Offset to PORTC register */
	twi.ddr = (uint8_t *)0x27;	/* Offset to DDRC register */
	twi.sda = PC4;
	twi.scl = PC5;
	XG_TWIInit(&twi, 0x7A, F_CPU, TWI_CLOCK);

	/* Configure pins as input/output ones. */
	DDRD = 0x00;
	SET_BIT(DDRD, OLED_RES);		/* output */
	SET_BIT(DDRD, OLED_PWR);		/* output */
	CLEAR_BIT(DDRD, BTN1);			/* input */
	CLEAR_BIT(DDRD, BTN2);			/* input */
	CLEAR_BIT(DDRD, BTN3);			/* input */

	/* Set initial values. */
	SET_BIT(PORTD, OLED_RES);
	CLEAR_BIT(PORTD, OLED_PWR);
	_delay_ms(1);

	/* We've to switch OLED on. */
	CLEAR_BIT(PORTD, OLED_RES);
	_delay_ms(1);
	SET_BIT(PORTD, OLED_RES);
	_delay_ms(1);
	SET_BIT(PORTD, OLED_PWR);
	_delay_ms(100);
	/* Setup OLED display */
	XG_SSD1309TWIInit(&twi, &display);

	/* Setup Timer/Counter2 to count milliseconds */
	timer2_init();
	sei();

	i = 0;
	while (1) {
		XG_SSD1309SetPage(&display, 0);
		XG_SSD1309SetColumn(&display, 0);

		XG_TWIStart(&twi);
		XG_TWIWrite(&twi, 0x40);
		delay_ms = ms;
		for (j = 0; j < FRAME_ITER; j++) {
			for (i = 0; i < sizeof oled_luci; i++) {
				XG_TWIWrite(&twi, pgm_read_byte(&oled_luci[i]));
			}
		}
		delay_ms = ms-delay_ms;
		XG_TWIStop(&twi);

		snprintf(textbuf, sizeof textbuf, "%lu.%lu",
		         FRAME_DIV/delay_ms, FRAME_DIV%delay_ms);
		XG_SSD1309SetPage(&display, 7);
		XG_SSD1309SetColumn(&display, 0);
		XG_SSD1309Print(&display, &textbuf[0]);
		_delay_ms(300);
	}
	return 0;
}

static void timer2_init(void)
{
	/* CTC mode, WGM22:0 = 2 */
	TCCR2A |= (1<<WGM21);
	TCCR2A &= ~(1<<WGM20);
	TCCR2B &= ~(1<<WGM22);

	/* OCR2A is 124 to gain 1kHz with selected prescaler */
	TCNT2 = 0;
	OCR2A = 124;
	/* Enable interrupt */
	TIMSK2 |= (1<<OCIE2A);

	/* Start timer, prescaler to Fclk_io/32: CS21:0 = 6 */
	TCCR2B |= (1<<CS21) | (1<<CS20);
	TCCR2B &= ~(1<<CS22);
}

ISR(TIMER2_COMPA_vect)
{
	ms++;
}

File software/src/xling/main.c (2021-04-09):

/*-
 * SPDX-License-Identifier: GPL-3.0-or-later
 *
 * This file is part of a firmware for Xling, a tamagotchi-like toy.
 *
 * Copyright (c) 2019 Dmitry Salychev
 *
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
 * You should have received a copy of the GNU General Public License
 * along with this program.  If not, see <https://www.gnu.org/licenses/>.
 */
#define F_CPU			12000000UL	/* CPU 12 MHz */

#include <stdint.h>
#include <stdio.h>
#include <limits.h>
#include <avr/io.h>
#include <avr/interrupt.h>
#include <avr/pgmspace.h>
#include <avr/wdt.h>
#include <util/delay.h>

/*
 * Entry point of the Xling firmware.
 *
 * An initial configuration of the microcontroller will be performed here.
 * Tasks and FreeRTOS scheduler will be created and started here.
 *
 * NOTE: An interrupt of the 16-bit Timer 1 and its compare-match channel A is
 * used to generate a tick interrupt for the FreeRTOS scheduler.
 */

/* FreeRTOS headers. */
#include "FreeRTOS.h"
#include "task.h"
#include "queue.h"

/* SH1106 driver headers. */
#include "mcusim/drivers/avr-gcc/avr/display/sh1106/sh1106.h"

/* Xling headers. */
#include "xling/tasks.h"
#include "xling/graphics.h"
#include "xling/msg.h"

/* Local macros. */
#define SET_BIT(byte, bit)	((byte) |= (1U << (bit)))
#define CLEAR_BIT(byte, bit)	((byte) &= (uint8_t) ~(1U << (bit)))
#define IS_SET(byte, bit)	(((byte) & (1U << (bit))) >> (bit))
#define NEW_QUEUE(n)		(xQueueCreate((n), sizeof(xm_msg_t)))

/* Local variables. */
static xt_args_t _display_args;
static xt_args_t _battery_args;
static xt_args_t _sleep_args;
static xt_args_t _keyboard_args;
static uint8_t _mcusr_mirror
	__attribute__ ((section (".noinit")));

/* Local functions declarations. */
static void disable_wdt(void)
	__attribute__((naked))
	__attribute__((section(".init3")));

/* Entry point. */
int
main(void)
{
	TaskHandle_t *task_handle;
	int rc = 0;

	/* Configure PORTC pins as output. */
	DDRC = 0xFF;

	/* Configure PORTA pins as input. */
	DDRA = 0x00;
	PORTA = 0x00;

	/*
	 * Activate internal pull-up resistor for PB4 (SPI Slave Select)
	 * to ensure Master SPI operation.
	 */
	CLEAR_BIT(DDRB, PB4);
	SET_BIT(PORTB, PB4);

	/* Initialize arguments of the tasks. */
	_display_args.display_info.queue_handle = NEW_QUEUE(3);
	_display_args.battery_info.queue_handle = NEW_QUEUE(3);
	_display_args.sleep_info.queue_handle = NEW_QUEUE(3);
	_display_args.keyboard_info.queue_handle = NEW_QUEUE(3);

	/* Copy tasks arguments. */
	_battery_args = _display_args;
	_sleep_args = _display_args;
	_keyboard_args = _display_args;

	do {
		task_handle = &(_display_args.display_info.task_handle);
		rc = xt_init_display(&_display_args, 1, task_handle);
		if (rc != 0) {
			break;
		} else {
			_battery_args.display_info.task_handle = *task_handle;
			_sleep_args.display_info.task_handle = *task_handle;
			_keyboard_args.display_info.task_handle = *task_handle;
		}

		task_handle = &(_battery_args.battery_info.task_handle);
		rc = xt_init_battery_monitor(&_battery_args, 2, task_handle);
		if (rc != 0) {
			break;
		} else {
			_display_args.battery_info.task_handle = *task_handle;
			_sleep_args.battery_info.task_handle= *task_handle;
			_keyboard_args.battery_info.task_handle = *task_handle;
		}

		task_handle = &(_sleep_args.sleep_info.task_handle);
		rc = xt_init_sleep_mode(&_sleep_args, 2, task_handle);
		if (rc != 0) {
			break;
		} else {
			_display_args.sleep_info.task_handle = *task_handle;
			_battery_args.sleep_info.task_handle = *task_handle;
			_keyboard_args.sleep_info.task_handle = *task_handle;
		}

		task_handle = &(_keyboard_args.keyboard_info.task_handle);
		rc = xt_init_keyboard(&_keyboard_args, 3, task_handle);
		if (rc != 0) {
			break;
		} else {
			_display_args.keyboard_info.task_handle = *task_handle;
			_battery_args.keyboard_info.task_handle = *task_handle;
			_sleep_args.keyboard_info.task_handle = *task_handle;
		}
	} while (0);

	if (rc == 0) {
		/*
		 * Start the FreeRTOS scheduler.
		 */
		vTaskStartScheduler();
	}

	/* Stop the display driver. */
	MSIM_SH1106__drvStop();

	/*
	 * If all is well then main() will never reach here as the scheduler
	 * will now be running the tasks. If main() does reach here then it is
	 * likely that there was insufficient heap memory available for the
	 * display queue or tasks to be created.
	 */
	while (1);

	return 0;
}

/*
 * Note that for effectively any AVR that has the option to generate WDT
 * interrupts, the watchdog timer remains active even after a system reset
 * (except a power-on condition), using the fastest prescaler value
 * (approximately 15 ms).
 *
 * It is therefore required to turn off the watchdog early during program
 * startup.
 *
 * NOTE: https://www.nongnu.org/avr-libc/user-manual/group__avr__watchdog.html
 */
static void
disable_wdt(void)
{
	/*
	 * Saving the value of MCUSR in mcusr_mirror is only needed if the
	 * application later wants to examine the reset source, but in
	 * particular, clearing the watchdog reset flag before disabling the
	 * watchdog is required, according to the datasheet.
	 */
	_mcusr_mirror = MCUSR;
	MCUSR = 0;

	wdt_disable();
}

/*
 * Disable interrupts and sit still in case of a stask overflow.
 *
 * NOTE: This hook will be optimized out by the compiler unless you have
 * a "configCHECK_FOR_STACK_OVERFLOW" option enabled in the FreeRTOSConfig.h.
 */
void
vApplicationStackOverflowHook(TaskHandle_t *pxTask, signed char *pcTaskName)
{
	taskDISABLE_INTERRUPTS();
	while(1);
}

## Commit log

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2017-11-07 patch 0.1.1: Add missing component values in schematic.
    [xling.sch]
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2017-11-14 patch 0.1.8: Add other OLED and DCDC 3V-to-12V.
    [xling.kicad_pcb, xling.sch]
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2017-11-18 patch 0.1.11: Add OSHW and 1KIB logos to the PCB.
    [xling.kicad_pcb, xling.sch]
2017-11-18 patch 0.1.12: Remove all dummy elements from PCB design.
    [xling.kicad_pcb, xling.sch]
2017-11-19 patch 0.1.13: Adjust silk screen text to include into Gerber files.
    [xling.kicad_pcb, xling.sch]
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2017-12-25 patch 0.1.15: Fix battery charging scheme.
    [xling.sch]
2018-01-19 patch 0.1.16: Add 'Model' field to all schematic components to point selected model clearly.
    [xling.sch]
2018-01-23 patch 0.1.17: Add 3.3V linear regulator for USB mode.
    - Fix placement of U1 (mirrored);
    - Fix placement of the AVR ISR connector;
    - Adjust U3 pads to easy soldering (they are a bit bigger now);
    - Add marks for D1 and D2 LEDs;
    - Replace models of several components to be in 0805 or 0603 cases;
    - Add fixed linear 3.3V voltage regulator for USB mode;
    - Re-route PCB according to the all of these changes.
    [xling.kicad_pcb, xling.sch]
2018-03-20 Add missing footprints.
2018-04-20 patch 0.1.18: Add new KiCad modules and scheme changes.
    [xling.kicad_pcb, xling.sch]
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2018-05-27 patch 0.1.20: Update PCB and prepare gerber files for production.
    [xling-0.1.13-B.Cu.gbl, xling-0.1.13-B.Paste.gbp, xling-0.1.13-B.SilkS.gbo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]
2018-06-24 patch 0.1.21: Correct exact models of the components in schematic.
    [xling.kicad_pcb, xling.sch]
2018-07-12 patch 0.1.22: Power supply scheme modified and PCB update.
    [xling-0.1.20-B.Cu.gbl, xling-0.1.20-B.Mask.gbs, xling-0.1.20-B.Paste.gbp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]
2018-11-02 patch 0.2.0: Update hardware files to KiCad 5.
    This patch brought a firmware part of the project to perform any tests
    only. It draws two different pictures on an OLED display and counts
    frames per second.
    Schematic was updated to include a new DC-DC buck converter (AP3401) to
    produce 3.3V from both USB and a battery. Choosing this converter is a
    trade-off between an expensive buck-boost converter which can operate
    correctly at 3.2V voltage level of almost depleted battery and a cheap buck
    converter which produces 3.3V from the input voltage which should be above
    the required level.
    There is also a python plugin in hardware/plugins directory to generate a BOM
    html file. It can be added to a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
    [xling.kicad_pcb, xling.sch]
2018-11-02 patch 0.2.0001: Adjust some footprints.
    Several footprints were updated to use rounded rectangles instead of
    rectangles with sharp corners as pads.
    BOM generator script updated to include a revision into a BOM html file.
    It is useful to understand which components are required for a specific
    version of the device.
    There is a new TSOT26 footprint created and added especially for AP3401
    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
    [xling.sch]
2018-11-03 patch 0.2.0002: Update PCB.
    Components placed according to their updated footprints. The most
    noticible ones are IDC connecter of the AVR ISP and a horizontal battery
    connector. There are many minor changes and no routing yet.
    [xling.kicad_pcb, xling.sch]
2018-11-04 patch 0.2.0003: Updated PCB.
    This is an updated version of PCB which is almost ready for production.
    It contains new footprints for AVR ISP connector, a battery connector and
    an MCUSim logo.
    There are also many GND vias generated using a python plugin from
    https://github.com/jsreynaud/kicad-action-scripts.
    [xling.kicad_pcb, xling.sch]
2018-11-04 patch 0.2.0004: Updated footprints.
    Several footprints were updated to replaced rectangle pads with
    rounded-corner pads. Minor PCB changes were made also.
    Bill of materials can be found in the hardware directory.
    [xling.kicad_pcb, xling.sch]
2019-03-30 patch 0.2.5: New OLED.
    There is a huge change in a circuit to replace an OLED and fix multiple
    mistakes and improve it a bit.
    [Bottom_case_v8.FCStd, Device_case_v8.FCStd, Device_case_v9.FCStd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]
2019-04-01 patch 0.2.6: Update and add missing footprints.
    ticket: N/A
    There new models/parts found for micro switches and a connector for AVR
    in-circuit system programmer.
    [xling.sch]
2019-04-04 patch 0.2.7: PCB adjustments.
    There are some modifications to make a new version of the PCB ready for
    manufacturing.
    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
    [xling.kicad_pcb, xling.sch]
2019-04-04 patch 0.2.8: Add micro USB 3D model.
    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
    [xling.kicad_pcb, xling.sch]
2019-04-04 patch 0.2.9: New battery SMD footprint.
    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
    [xling.kicad_pcb, xling.sch]
2019-04-04 patch 0.2.10: Add gaps to mount PCB correctly.
    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
    [xling.kicad_pcb, xling.sch]
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2019-04-05 patch 0.2.12: Make a gap for OLED FFC bigger.
    There is also a 3D package for Molex PicoFlex connector for AVR ISP.
    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
    [Molex_504050-0691.stp, xling.kicad_pcb, xling.sch]
2019-04-05 patch 0.2.13: Add 3D model for micro tacts.
    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
    [Switch_TVCM09.stp, xling.kicad_pcb, xling.sch]
2019-04-05 patch 0.2.14: Add board info and a name (silk).
    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
    [xling.kicad_pcb, xling.sch]
2019-04-05 patch 0.2.15: Remove unused gap on PCB.
    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
    [xling.kicad_pcb, xling.sch]
2019-04-19 patch 0.2.16: Fix crystal footprint.
    There are multiple fixes and adjustments performed. Among the others:
    - Battery footprint improved to better wiring and soldering;
    - Silkscreen fixed on the many footprints (including 0603 caps and res);
    - Crystal footprint fixed;
    - Test points for the GND, +3.3V and Vbat added.
    [xling-0.1.20-B.Cu.gbl, xling-0.1.20-B.Mask.gbs, xling-0.1.20-B.Paste.gbp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]
2019-09-19 patch 0.3: A new ATmega1284p-based PCB.
    This is a new version of the whole board which is based on ATmega1284p
    now. The most noticible changes:
    - A new ATmega1284p microcontroller (128 KiB flash, 16 KiB SRAM),
    - OLED is connected via 3-wire SPI (instead of I2C earlier),
    - A new version of PCB has been re-routed from scratch,
    - An artwork for a bottom PCB layer provided by SierraSaura
    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
    [Bottom_case_v8.FCStd, Device_case_v8.FCStd, Device_case_v9.FCStd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]
2019-11-17 patch 3.1: More checkpoints and 4-wire SPI.
    This is the first commit after version adjustment and in a new
    current/3.0 branch. All of the changes in the third iteration of the
    Xling PCB will find their place in this branch.
    Starting from Xling PCB v3.1, new checkpoints are available:
    +3.3V - output voltage of the power supply block and AP3401
    particularly;
    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
    [AP3401.stp, MCP73831.stp, Molex_504050-0691.stp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]
2020-01-16 patch 3.2: Minor PCB changes.
    - Buttons are placed according to the new case configuration;
    - BTN3 pin assigned to pin 42 (INT2) of the MCU;
    - A new silkscreen artwork based on U2Pi's work from deviantart;
    - A narrow deeping on the left is a bit wider;
    [xling-B.Cu.gbl, xling-B.Mask.gbs, xling-B.Paste.gbp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]
2020-03-27 Road to OSHWA certification.
    This is the first commit in the current/4.0 branch which brings a lot of
    changes which are supposed to gather all files in one place and open a road
    to OSHWA certification.
    Structure of the repository changed. It contains all of the necessary
    design documents, firmware source code and other files to let everyone
    make the device.
    Repository includes the firmware of the version 0.4.12 which
    means that two critical bugs when Xling hangs fixed.
    KiCad project, schematic and board designs are distrubuted under the
    terms of CERN Open Hardware Licence Version 2 - Weakly Reciprocal
    starting from hardware revision 4.
    [AP3401.stp, Bottom_case_v8.FCStd, Device_case_v8.FCStd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]
2020-03-29 Update labels on silkscreen.
    Size and position of the silkscreen text have been adjusted to improve
    readability.
    [xling.kicad_pcb]
2020-03-29 Switch to tasks notification API.
    Problem:
    Xling hangs from time to time during wake ups. There are no display updates
    via SPI either (checked by Saleae Logic 8).
    Solution:
    Get rid of the direct control functions to manipulate the tasks like
    vTaskSuspend() and vTaskResume() in favor of the tasks notification API
    including xTaskNotify(), xTaskNotifyFromISR() and xTaskNotifyWait().
    There is a simple latching mechanism for ISRs of the Sleep Mode task
    has been implemented to prevent hangs also.
    Brown-out Detector (BOD) is disabled during sleep mode.
    [battery_monitor_task.c, display_task.c]
2020-05-15 Graphics API function to paint images on a canvas.
    There is a need for a function to paint images at the arbitrary
    coordinates on a canvas which can be transferred to the OLED
    display. It could help to develop graphics engine for Xling also.
    A new MSIM_SH1106_Draw_PF() function which allows to paint an image
    from flash memory to an image buffer (canvas) located in RAM at the
    arbitrary coordinates.
    It helps to hide a page-based memory organization of the display's
    graphic RAM and allows to focus on pixel coordinates.
    You'll find declaration of the function in
    "mcusim/drivers/avr-gcc/avr/display/sh1106/sh1106_graphics.h".
    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
    [battery_monitor_task.c, display_task.c]
2020-05-19 Tweak task priorities to avoid display freezing.
    Xling tends to freeze updates of the display with the previous
    version of the firmware.
    Priorities of the Sleep Mode and Battery Monitor tasks have been
    lowered by 1, and all of the tasks with their priorities look like:
    3 -> Keyboard task (highest)
    2 -> Battery Monitor task
    2 -> Sleep Mode task
    1 -> Display task (lowest)
    Frequency of the Display task is controlled by a call to vTaskDelayUntil()
    instead of the timer interrupt now.
    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
    [battery_monitor_task.c, display_task.c, main.c]
2020-07-12 Tweaks to paint text with different fonts.
    It might be necessary to paint text with different fonts generated by
    LCD Image Converter.
    There is a specific font template prepared for LCD Image Converter
    (see common/lcd-image-converter/Xling_font_template.tmpl). Several tweaks
    to the SH1106 graphics functions have been finished in order to paint
    text with such fonts.
    Note:
    There is a patch for LCD Image Converter which adds a new
    "out_blocks_offset" tag to the templates. It's necessary to have a patched
    version of the converter to generate new fonts for Xling.
    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
    [battery_monitor_task.c, display_task.c]
2020-09-06 Plugin for GIMP to export image as a scene.
    Composing new scenes for Xling takes time to finish it manually.
    It might also be useful to design scenes for Xling visually using GIMP,
    for example.
    Plugin for GNU Image Manipulation Program (GIMP) to export an existing
    image with different layers as a scene for Xling to be compiled directly,
    without any additional tweaks. See common/gimp/xlingtool.c and
    common/gimp/xlingtool.org for details.
    Note that different layers are referred by their SHA-1 hash calculated
    based on their actual image data. It helps to de-duplicate layers data
    (i.e. minimize flash memory usage) and re-use them wit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
    [display_task.c]
2020-09-12 Update Xling PCB to revision 4.
    It's hard to solder battery pads on the previous versions of the Xling
    PCB. Battery pins can easily be shorted and the battery itself might be
    damaged.
    Buttons in the previous revision can also be damaged easily because of
    the membrane which can be ripped off.
    Solution
    There is a new connector for battery (Molex 202656-0021) and new
    buttons (TVCU11BB) with a shield.
    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
    [Bottom_case.FCStd, Bottom_case.amf, Button.FCStd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]
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2020-09-13 Little tweaks to Xling PCB rev.4
    There was no way to reset MCU without a programmator or a custom
    connector to ICSP.
    A solder jumper to reset MCU added to the top side of the board.
    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
    [xling-B_Cu.gbl, xling-B_Mask.gbs, xling-B_Paste.gbp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]
2020-09-17 WIP to support animations in Xlingtool.
    Xlingtool, a plugin for GIMP, doesn't have a way to define and
    export animations in scenes for Xling.
    Work-in-progress for Xlingtool to implement an ability to
    define and link animation frames together in order to export them as
    a single animation as a part of the whole scene.
    A scene animation can be defined as a set of consecutive image
    layers with special names like:
    !anim(name, path1)_..._01
    !anim(name, path1)_..._02
    !anim(name, path2)_..._03
    !anim(name, path3)_..._04
    where "name" - is a name of the animation, "pathX" - one of the
    animation paths where the current animatio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
2020-09-23 WIP to support animations in Xlingtool.
    It is possible to track indexes of the frames within animation which
    will help to export animations to Xling firmware easily.
    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
    [Bottom_case.stl, Button.stl, Top_case.stl]
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2021-01-01 Animations and keyboard callback in Xlingtool.
    Xlingtool, a plugin for GIMP to export scenes for Xling, can process
    several new tags from the layer names including:
    - !anim(anim_name, anim_path)
    - !stay(frames_to_stay)
    - !go(anim_path, chance_to_go)
    These tags helps to create a complex, multipath animation on a scene
    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
    [xling.sch]
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2021-01-13 A finished "smoking_02" scene.
    There is a common/images/scenes/smoking_02.xcf finished, exported
    using Xlingtool and added to the project in
    software/include/xling/scenes.
    Another important change is a FreeRTOS kernel tick rate changed from
    1000 Hz to 500 Hz. It doesn't affect a behavior of the whole device,
    but allows to waste less time on context switches.
2021-04-04 Update Xling schematic and PCB to v4.1.
    There were too many routes in the ground copper layer which
    formed an obstacle for return currents. Molex Pico-EZmate header
    (2026560021) proved to be easy to solder, but really hard to
    solder battery pins for it.
    All of the long routes have been removed from the ground layer and
    only short "jumpers" left in order to simplify routing on the
    signal/power layer.
    A footprint to manually solder battery pins has been re-worked
    and returned back to PCB. Footprint for previous version of the
    buttons has been returned back also.
    Footprints for test points have been replaced with a smaller circle
    version (0.5 mm vs 2.0 mm pre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
    [Xling_v3.2_bom.csv, Xling_v3.2_bom.ods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]
2021-04-09 Export several scenes together by Xlingtool plugin.
    GIMP can have several images (scenes) opened, but only current
    one is exported by Xlingtool previously. It is a problem when
    several scenes have been prepared for Xling and should be
    exported together into anim.h and scenes.h files.
    Xlingtool has been modified to process all of the currently
    open images in GIMP by applying its checks one by one. No
    context is preserved between then, but only anim.h and
    scenes.h are kept open and closed after all of the scenes exported.
    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
    [battery_monitor_task.c, display_task.c, main.c]
2021-05-03 Draw animated speech.
    A lack of a way to draw animated text/speech didn't allow Exy
    to interact with a player and attract her attention to any
    in-game objects or events.
    A new function xg_draw_speech() added to src/xling/graphics.c
    to be called periodically (as xg_draw_scene() does). There're
    two new modes XG_SM_SCENE and XG_SM_SPEECH added to
    xg_scene_ctx_t to draw scene and speech accordingly.
    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
    [display_task.c]

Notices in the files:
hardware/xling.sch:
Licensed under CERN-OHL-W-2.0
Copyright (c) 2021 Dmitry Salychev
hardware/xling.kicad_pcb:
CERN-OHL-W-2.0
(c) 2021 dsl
